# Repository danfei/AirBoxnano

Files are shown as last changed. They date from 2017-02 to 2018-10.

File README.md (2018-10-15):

AirBoxnano
============
This project uses the Plantower PMS5003S to detect PM2.5 and HCHO in the air.

Photo
------------
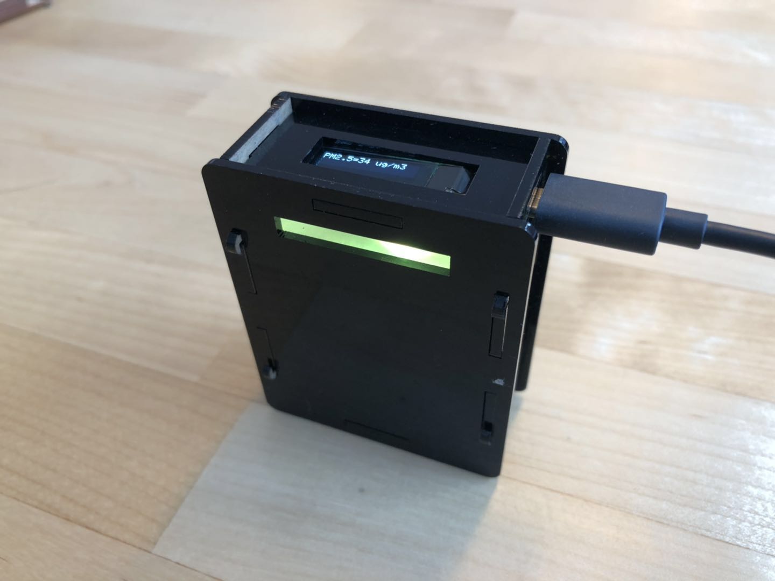
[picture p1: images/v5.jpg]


Schematic
------------
[PDF][schem]

BOM
------------
[CSV][bom]

Laser cut
------------
[DXF][lc]

PCB
------------
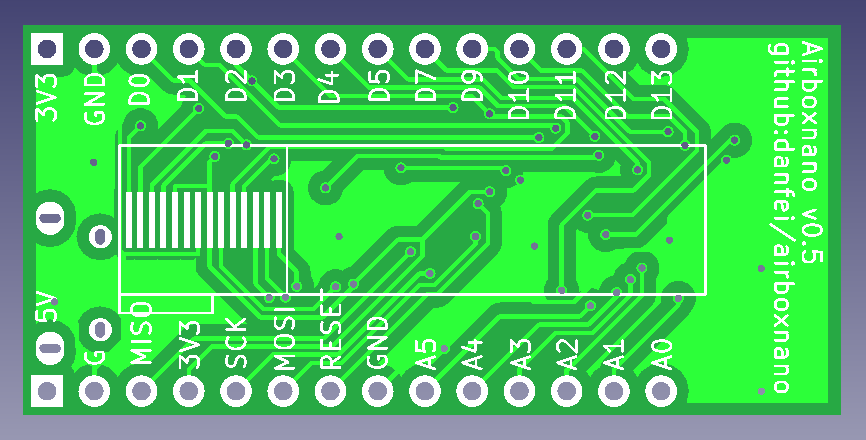
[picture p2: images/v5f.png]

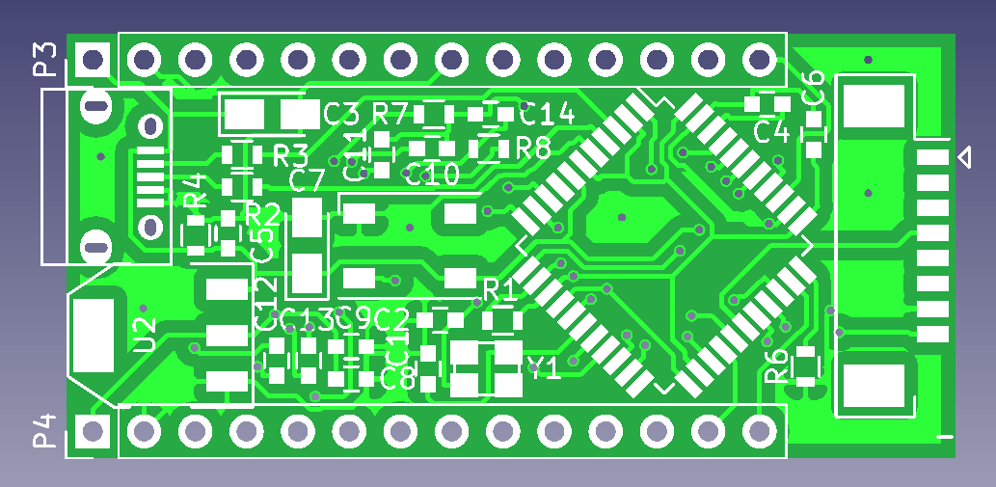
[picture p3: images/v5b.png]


License
------------
This project is released under the CC BY-SA license.


Support
------------
df4v@qq.com

[schem]:https://github.com/danfei/AirBoxnano/raw/master/hardware/AirBoxnano.pdf
[bom]:https://github.com/danfei/AirBoxnano/raw/master/manufacturing/AirBoxnano_bom.csv
[lc]:https://github.com/danfei/AirBoxnano/raw/master/manufacturing/airboxnano.dxf

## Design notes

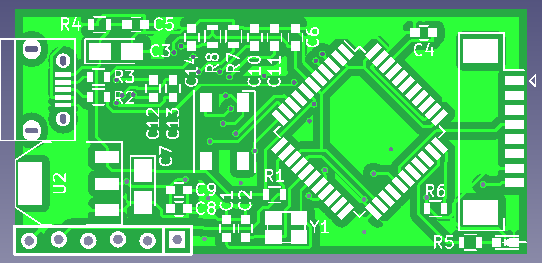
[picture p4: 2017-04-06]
images/v3f.png

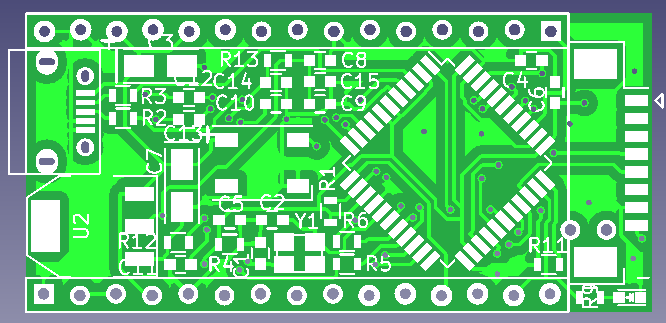
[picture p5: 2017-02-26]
images/v1b.png

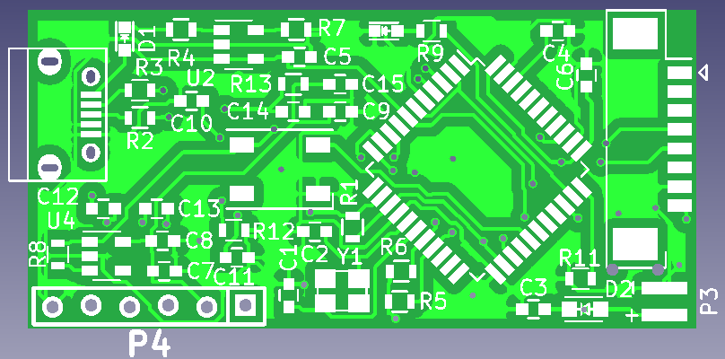
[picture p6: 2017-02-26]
images/v2b.png

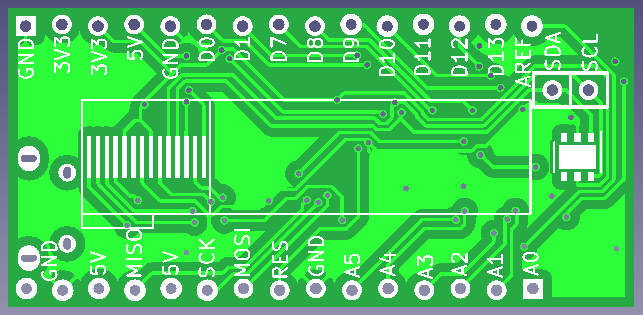
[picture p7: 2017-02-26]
images/v1f.png

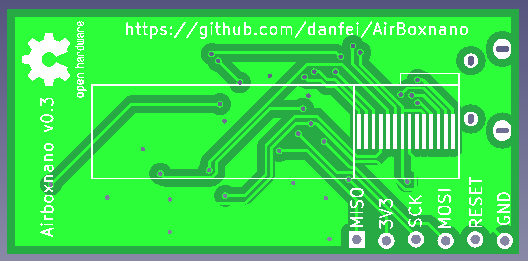
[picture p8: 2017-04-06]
images/v3b.png

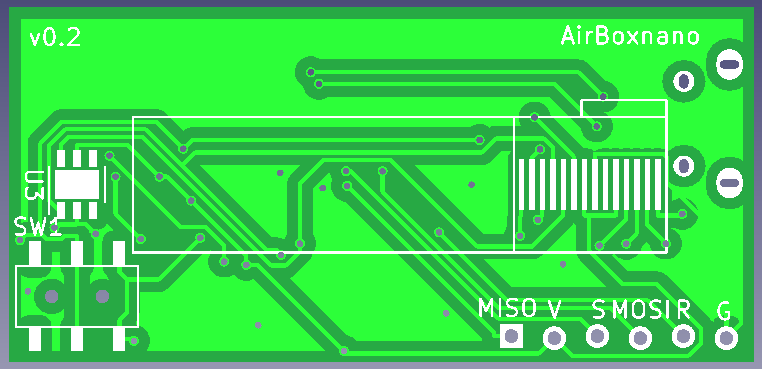
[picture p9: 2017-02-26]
images/v2f.png

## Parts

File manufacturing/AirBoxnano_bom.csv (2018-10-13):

Comment | Footprint | Designator
NCP1117ST33T3G | SOT-223 | U2
22P | C_0603 | C1,C2
22uF | Tantalum_Case-A_EIA-3216-18_Reflow | C3
100nF | C_0603 | C4,C5
1uF | C_0603 | C6,C12,C13
10uF/25V | Tantalum_Case-A_EIA-3216-18_Reflow | C7
10uF | C_0603 | C8
4.7uF | C_0603 | C9,C10,C11,C14
1K | R_0603 | R1,R6
22R | R_0603 | R2,R3
10K | R_0603 | R4,R8
820K | R_0603 | R7
16MHz | crystal_FA238-TSX3225 | Y1

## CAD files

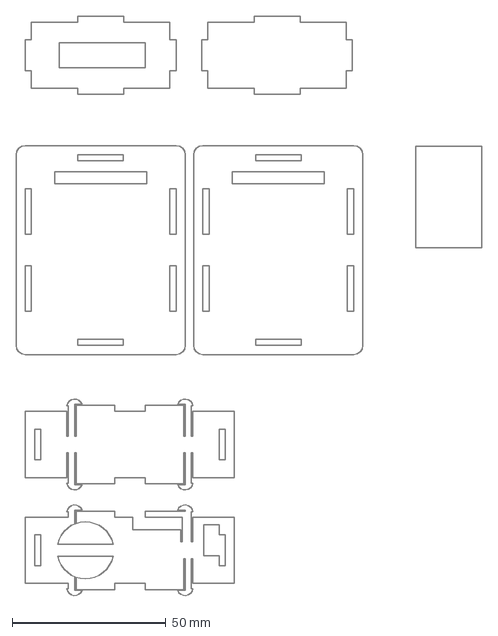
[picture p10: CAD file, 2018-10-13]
manufacturing/airboxnano.dxf
151.5 x 188.6 mm

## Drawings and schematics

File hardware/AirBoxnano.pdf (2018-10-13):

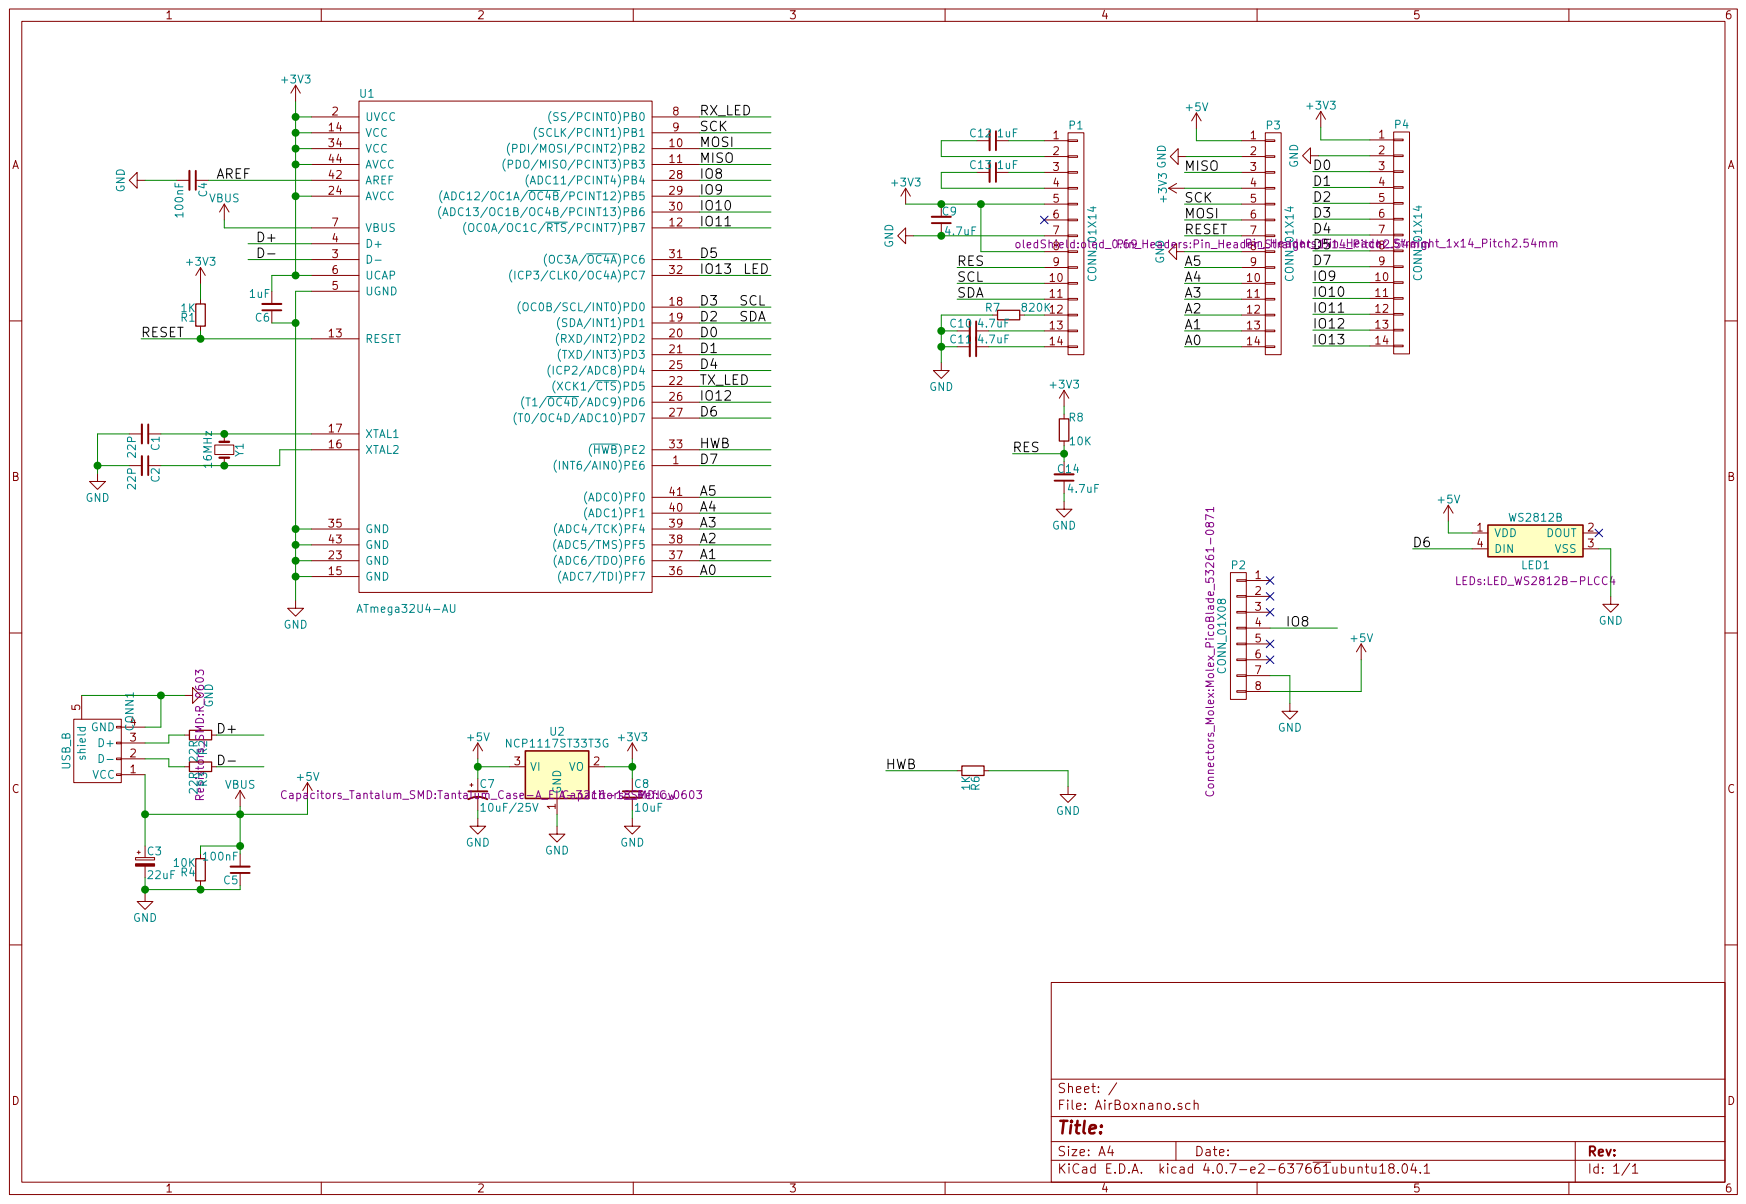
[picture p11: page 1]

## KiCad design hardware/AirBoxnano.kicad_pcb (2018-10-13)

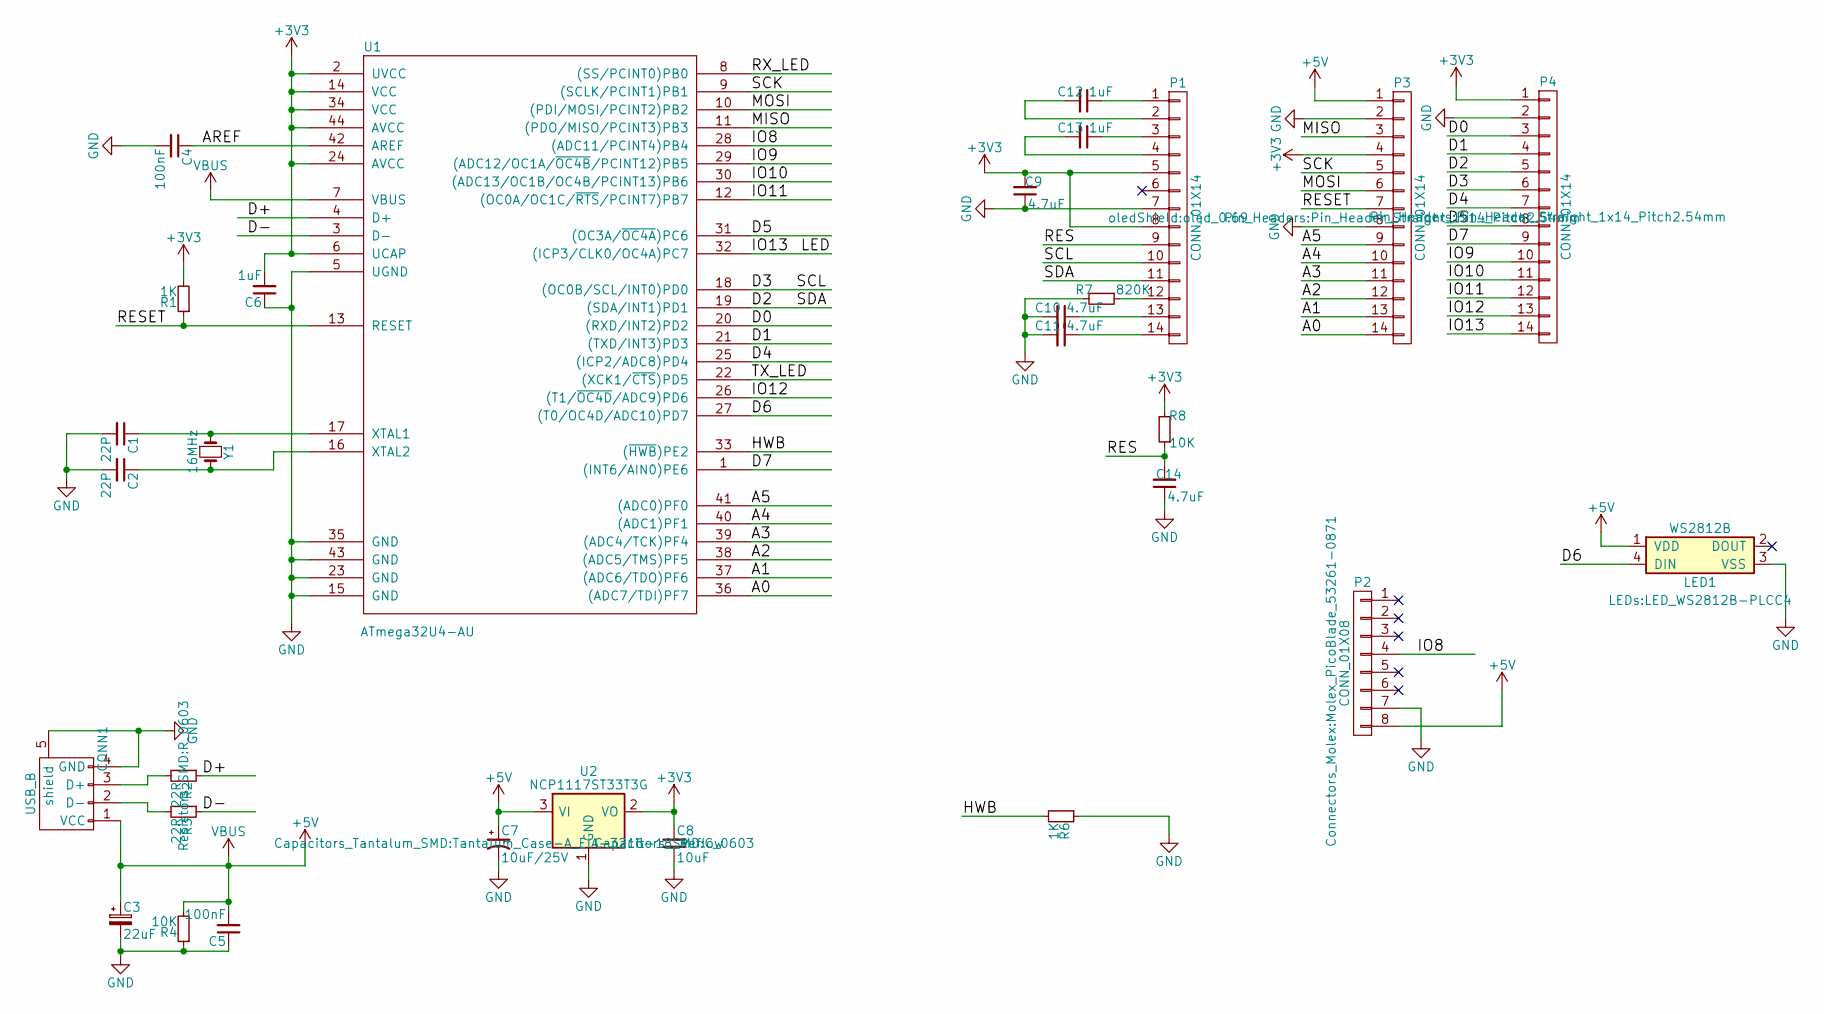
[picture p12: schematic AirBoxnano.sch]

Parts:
C1, C2: 22P; C_0603
C3: 22uF; Tantalum_Case-A_EIA-3216-18_Reflow
C4, C5: 100nF; C_0603
C6, C12, C13: 1uF; C_0603
C7: 10uF/25V; Tantalum_Case-A_EIA-3216-18_Reflow
C8: 10uF; C_0603
C9, C10, C11, C14: 4.7uF; C_0603
CONN1: USB_B; USB_Micro-B
LED1: WS2812B; LED_WS2812B-PLCC4
P1: CONN_01X14; oled_0.69
P2: CONN_01X08; Molex_PicoBlade_53261-0871
P3, P4: CONN_01X14; Pin_Header_Straight_1x14_Pitch2.54mm
R1, R6: 1K; R_0603
R2, R3: 22R; R_0603
R4, R8: 10K; R_0603
R7: 820K; R_0603
U1: ATmega32U4-AU; TQFP-44_10x10mm_Pitch0.8mm
U2: NCP1117ST33T3G; SOT-223
Y1: 16MHz; crystal_FA238-TSX3225

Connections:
+3V3: C6.2, C8.1, C9.2, P1.5, P1.8, P3.4, P4.1, R1.2, R8.2, U1.2 (UVCC), U1.6 (UCAP), U1.14 (VCC), U1.24 (AVCC), U1.34 (VCC), U1.44 (AVCC), U2.2 (VO)
+5C: C3.1, C5.2, C7.1, CONN1.1 (VCC), LED1.1 (VDD), P2.8, P3.1, R4.2, U1.7 (VBUS), U2.3 (VI)
/A0: P3.14, U1.36 ((ADC7/TDI)PF7)
/A1: P3.13, U1.37 ((ADC6/TDO)PF6)
/A2: P3.12, U1.38 ((ADC5/TMS)PF5)
/A3: P3.11, U1.39 ((ADC4/TCK)PF4)
/A4: P3.10, U1.40 ((ADC1)PF1)
/A5: P3.9, U1.41 ((ADC0)PF0)
/AREF: C4.1, U1.42 (AREF)
/D0: P4.3, U1.20 ((RXD/INT2)PD2)
/D1: P4.4, U1.21 ((TXD/INT3)PD3)
/D2: P1.11, P4.5, U1.19 ((SDA/INT1)PD1)
/D3: P1.10, P4.6, U1.18 ((OC0B/SCL/INT0)PD0)
/D4: P4.7, U1.25 ((ICP2/ADC8)PD4)
/D5: P4.8, U1.31 ((OC3A/~OC4A~)PC6)
/D6: LED1.4 (DIN), U1.27 ((T0/OC4D/ADC10)PD7)
/D7: P4.9, U1.1 ((INT6/AIN0)PE6)
/D+: R2.1, U1.4 (D+)
/D-: R3.1, U1.3 (D-)
/HWB: R6.2, U1.33 ((~HWB~)PE2)
/IO8: P2.4, U1.28 ((ADC11/PCINT4)PB4)
/IO9: P4.10, U1.29 ((ADC12/OC1A/~OC4B~/PCINT12)PB5)
/IO10: P4.11, U1.30 ((ADC13/OC1B/OC4B/PCINT13)PB6)
/IO11: P4.12, U1.12 ((OC0A/OC1C/~RTS~/PCINT7)PB7)
/IO12: P4.13, U1.26 ((T1/~OC4D~/ADC9)PD6)
/IO13: P4.14, U1.32 ((ICP3/CLK0/OC4A)PC7)
/MISO: P3.3, U1.11 ((PDO/MISO/PCINT3)PB3)
/MOSI: P3.6, U1.10 ((PDI/MOSI/PCINT2)PB2)
/RES: C14.2, P1.9, R8.1
/RESET: P3.7, R1.1, U1.13 (RESET)
/SCK: P3.5, U1.9 ((SCLK/PCINT1)PB1)
GND: C1.2, C2.2, C3.2, C4.2, C5.1, C6.1, C7.2, C8.2, C9.1, C10.2, C11.2, C14.1, CONN1.4 (GND), CONN1.5 (shield), LED1.3 (VSS), P1.7, P2.7, P3.2, P3.8, P4.2, R4.1, R6.1, R7.2, U1.5 (UGND), U1.15 (GND), U1.23 (GND), U1.35 (GND), U1.43 (GND), U2.1 (GND)
unnamed: C1.1, U1.17 (XTAL1), Y1.1
unnamed: C2.1, U1.16 (XTAL2), Y1.2
unnamed: C10.1, P1.13
unnamed: C11.1, P1.14
unnamed: C12.1, P1.1
unnamed: C12.2, P1.2
unnamed: C13.1, P1.3
unnamed: C13.2, P1.4
unnamed: CONN1.2 (D-), R3.2
unnamed: CONN1.3 (D+), R2.2
unnamed: P1.12, R7.1

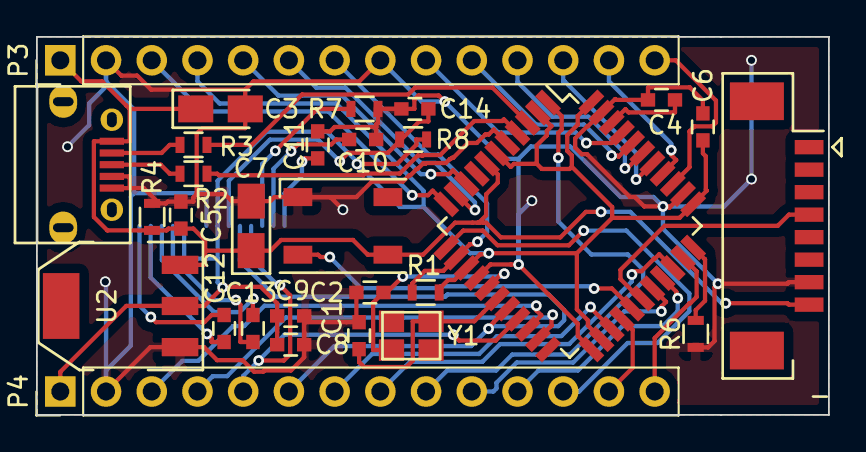
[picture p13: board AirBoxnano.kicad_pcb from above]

Board: 2 copper layers, 44.0 x 21.0 mm, 30 parts (1 on the bottom side), 43 nets.

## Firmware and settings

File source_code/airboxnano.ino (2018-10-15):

#include <Thread.h>
#include <SoftwareSerial.h>
#include <Adafruit_GFX.h>
#include <Adafruit_SSD1306.h>
#include <Wire.h>
#include <Adafruit_NeoPixel.h>

#define PIN 6

Thread PMThread = Thread();
Thread LEDThread = Thread();

#define OLED_RESET 4
Adafruit_SSD1306 display(OLED_RESET);

#if (SSD1306_LCDHEIGHT != 16)
#error("Height incorrect, please fix Adafruit_SSD1306.h!");
#endif

SoftwareSerial PMsensor(8,7);
int pm1_0, pm2_5, pm10_0;
float hcho;
//PM2.5
struct _panteng {
    unsigned char len[2];
    unsigned char pm1_0_cf1[2];
    unsigned char pm2_5_cf1[2];
    unsigned char pm10_0_cf1[2];
    unsigned char pm1_0[2];
    unsigned char pm2_5[2];
    unsigned char pm10_0[2];
    unsigned char d1[12];
    unsigned char hcho[2];
    unsigned char d2[2];
} panteng;

char str[100];
void PMCallback(){
  unsigned char c;
  static int state = 0;
  static int count = 0;
  //static int time=0;
  //int i;Serial.println("GO!");
      while (PMsensor.available()) {
        c = PMsensor.read();
        //Serial.print(c);Serial.print("--");
        //Serial.println(c,HEX);
        switch (state) {
            case 0:
                if (0x42 == c)
                    state = 1;
                break;
            case 1:
                if (0x4d == c) {
                    state = 2;
                    count = 0;
                }
                        break;
            case 2:
                ((unsigned char *) &panteng)[count++] = c;
                 if (count > 30) {
                    state = 0;
                    int pm1_0t,pm2_5t,pm10_0t;
                    pm1_0t = panteng.pm1_0[0] * 256 + panteng.pm1_0[1];
                    pm2_5t = panteng.pm2_5[0] * 256 + panteng.pm2_5[1];
                    pm10_0t = panteng.pm10_0[0] * 256 + panteng.pm10_0[1];
                    
                    int hash1 = 0x42+0x4d+panteng.len[0]+panteng.len[1]
                    +panteng.pm1_0_cf1[0]+panteng.pm1_0_cf1[1]+panteng.pm2_5_cf1[0]+panteng.pm2_5_cf1[1]+panteng.pm10_0_cf1[0]+panteng.pm10_0_cf1[1]
                    +panteng.pm1_0[0]+panteng.pm1_0[1]+panteng.pm2_5[0]+panteng.pm2_5[1]+panteng.pm10_0[0]+panteng.pm10_0[1]
                    +panteng.d1[0]+panteng.d1[1]+panteng.d1[2]+panteng.d1[3]+panteng.d1[4]+panteng.d1[5]+panteng.d1[6]+panteng.d1[7]+panteng.d1[8]+panteng.d1[9]+panteng.d1[10]+panteng.d1[11]+panteng.hcho[0]+panteng.hcho[1];
                    int hash2 = panteng.d2[0] * 256 + panteng.d2[1];
                    
                    
                    if(hash1 == hash2)
                    {
                      pm1_0 = pm1_0t;
                      pm2_5 = pm2_5t;
                      pm10_0 = pm10_0t;
                      hcho = ((float)(panteng.hcho[0] * 256 + panteng.hcho[1]))/1000.0; 
                      //Serial.print("hash");
                      //Serial.println(hash1,HEX);
                     }
                }
            break;
        default:
            break;
        }
    }
}

//LED

int RGBLED_r=0;
int RGBLED_g=0;
int RGBLED_b=255;
Adafruit_NeoPixel strip = Adafruit_NeoPixel(1, PIN, NEO_GRB + NEO_KHZ800);
void LEDCallback(){

strip.setBrightness(255);
strip.setPixelColor(0, RGBLED_r, RGBLED_g, RGBLED_b);
strip.show();
}
void setup()
{
  Wire.begin();
  
  PMThread.onRun(PMCallback);
  PMThread.setInterval(3000);

  LEDThread.onRun(LEDCallback);
  LEDThread.setInterval(800);
  
  Serial.begin(9600);
  PMsensor.begin(9600);
  
  display.begin(SSD1306_SWITCHCAPVCC, 0x3C);
  display.display();
  delay(3000);
  display.clearDisplay();
  delay(1000);
  strip.begin();
  strip.show();
}
 
 
void loop()
{
   if(PMThread.shouldRun())
    PMThread.run();
   if(LEDThread.shouldRun())
    LEDThread.run();
    
    display.setTextSize(1);
    display.setTextColor(WHITE);
    display.setCursor(0,0);
    
    Serial.println("    Air quality");
    snprintf(str,16, "PM1.0=%d ug/m3", pm1_0);
    Serial.println(str);
    snprintf(str,16, "PM2.5=%d ug/m3", pm2_5);
    Serial.println(str);
    display.println(str);
    snprintf(str,16, "PM10 =%d ug/m3", pm10_0);
    Serial.println(str);
    display.display();
    display.clearDisplay();
    delay(2000);
    
    snprintf(str,16, "HCHO =%d  mg/m3", hcho);
    Serial.println(str);
    display.setCursor(0,0);
    display.print("HCHO=");
    display.print(hcho);
    display.println(" mg/m3");
    display.display();
    display.clearDisplay();

    if(pm2_5<=30&&hcho<0.08){
    RGBLED_r=0;
    RGBLED_g=255;
    RGBLED_b=0;
  }
  if(pm2_5>30&&pm2_5<=60&&hcho<0.08){
    RGBLED_r=255;
    RGBLED_g=255;
    RGBLED_b=0;
  }
  if(pm2_5>60&&pm2_5<=90&&hcho<0.08){
    RGBLED_r=255;
    RGBLED_g=165;
    RGBLED_b=0;
  }
  if(pm2_5>90&&pm2_5<=120&&hcho<0.08){
    RGBLED_r=255;
    RGBLED_g=0;
    RGBLED_b=0;
  }
  if(pm2_5>120||hcho>=0.08){
    RGBLED_r=128;
    RGBLED_g=0;
    RGBLED_b=128;
  }
    delay(2000);
    
}

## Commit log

2017-02-26 update sch
    [AirBoxnano.sch]
2017-02-26 update footprint
    [AirBoxnano.sch]
2017-04-06 del temp/hum
    [AirBoxnano-B.Cu.gbr, AirBoxnano-B.Mask.gbr, AirBoxnano-B.SilkS.gbr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]
2018-10-13 Version 0.5
    [AirBoxnano-B.Cu.gbr, AirBoxnano-B.Mask.gbr, AirBoxnano-B.SilkS.gbr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]
